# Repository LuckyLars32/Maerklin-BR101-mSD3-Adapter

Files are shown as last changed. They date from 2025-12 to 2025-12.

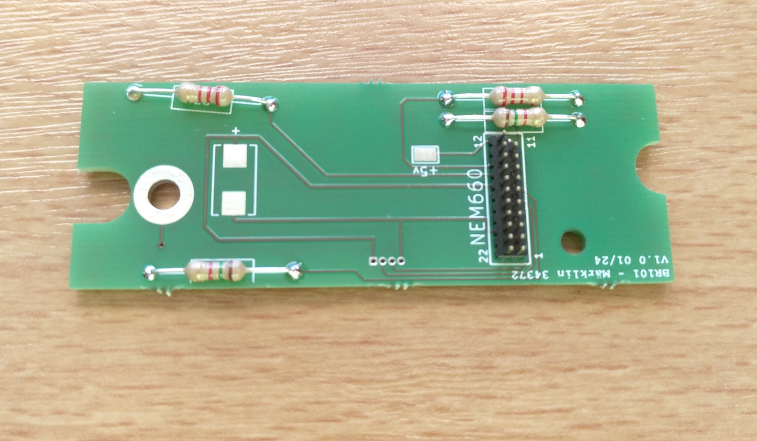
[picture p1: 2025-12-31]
BR101-mSD3-Adapterplatiene.png

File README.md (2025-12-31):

# Maerklin BR101 mSD3 Adapter
Adapterplatiene und Schallkapsel für den Einbau eines mSD3 Decoders + HLA in die Märklin BR101.  
Die Platine habe ich mit KiCAD Version 7.X erstellt.  
Die Schallkapsel habe ich mit einer 0.4er Düse, 0.2mm Layerhöhe und 50% Infill gedruckt.  

# Materialliste / BOM:
4x Widerstand 2,2 kΩ Bauform 0207 (der normale through-hole)  
1x 24 Pin Steckleiste (Push-Pull) gerade mit 1,27mm Raster  
1x Keramikkondensator 1206 (3216 metrisch) 1UF  
1x Märklin HLA Nachrüst Set 60941  
1x Märklin mSD3 oder anderer Sounddecoder mit NEM 660 Schnitstelle  
1x 15x11x3mm Lautsprecher 4-8 Ohm  

# Zusammenbau
Einbauseite immer wie Bedruckung auf der Platiene.
Die Wiederstände R1, R2, R3, R4 werden mit den 4x Widerstand 2,2 kΩ Bauform 0207 bestückt.
Die NEM660 Schnittstelle wird mit der 24 Pin Steckleiste mit 1,27mm Raster bestückt.
Der Keramikkondensator 1206 mit 1UF muss auf die Pads zwischen R1 und R3

# Pufferschaltung über mSD3 SUSI
Zusätzlich benötigte Komponenten:
2x Elko mit 500 - 1000 UF und max. 8,2 x 20 mm Radial
1x Schottkydiode mit 2 A Stromfestigkeit 25V Spannungsfestigkeit (mehr geht auch)
1x Widerstand 100 Ω
Zusammenbau:
Die beiden Elkos Paralell schalten. Dann die Scotty-Diode Parelell zum Wiederstand mit der + seite der Elkos verbinden.
Einbau:
Die Pufferschaltung dann mit +UB (+) und GND (-) auf der Adapterplatiene (bei eingebauter Platiene oben) verbinden.
Alternativ kann die Pufferschaltung auch an die Kontakte für den auf der Platiene integrierten Kondensator (bei eingebauter Platiene unten) angeschlossen werden. 
Diese Lötpads sind ebenso mit +UB und GND verbunden.

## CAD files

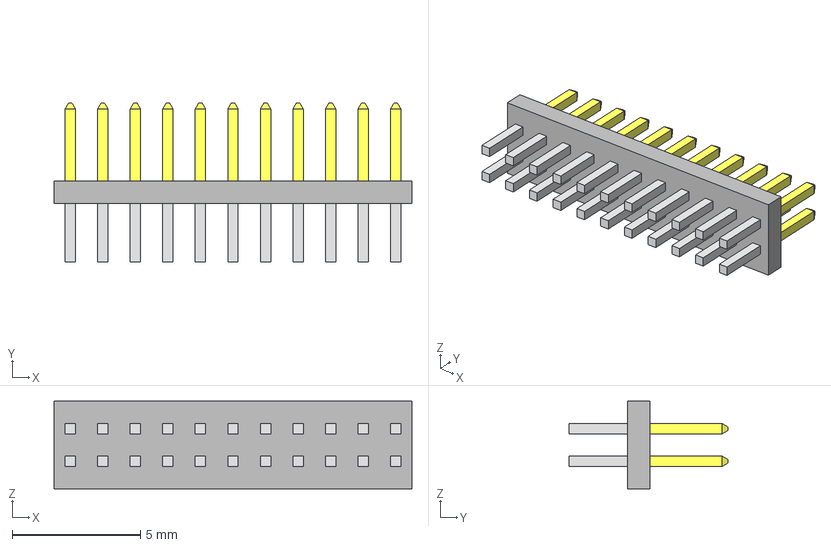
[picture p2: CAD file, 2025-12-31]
Maerklin_sMD3_Traegerplatiene_BR101/MaerklinConnectors/SAMTEC-FTS-111-01-X-D.step
14.0 x 6.20 x 3.43 mm
FTS-111-01-L-D_pins2
FTS-111-01-L-D_pins1
FTS-111-01-L-D_body

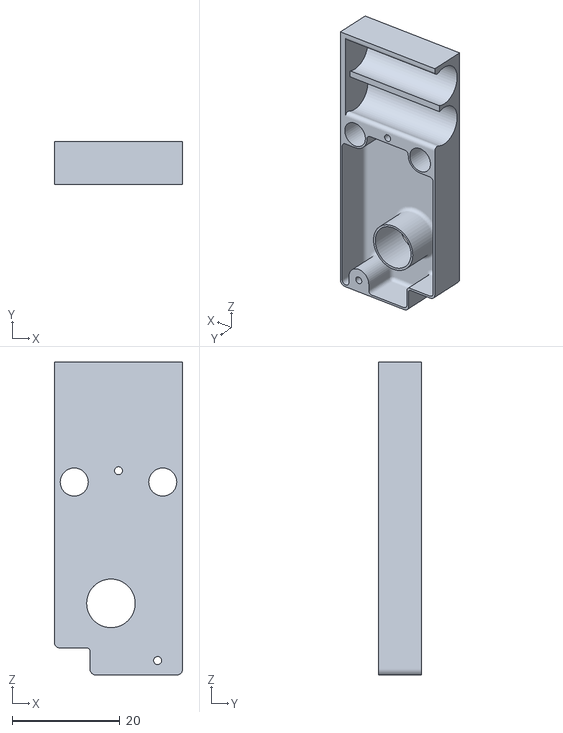
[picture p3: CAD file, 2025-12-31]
Schallkapsel/SchallkapselBR101.stl
23.8 x 8.00 x 58.0

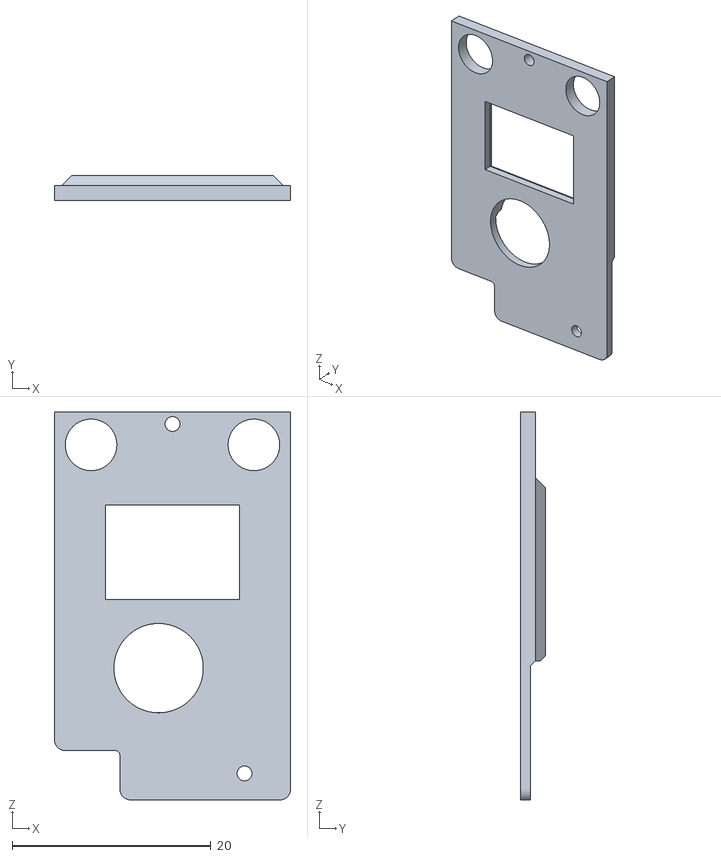
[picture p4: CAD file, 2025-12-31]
Schallkapsel/SchallkapselDeckelBR101.stl
23.8 x 2.50 x 39.1

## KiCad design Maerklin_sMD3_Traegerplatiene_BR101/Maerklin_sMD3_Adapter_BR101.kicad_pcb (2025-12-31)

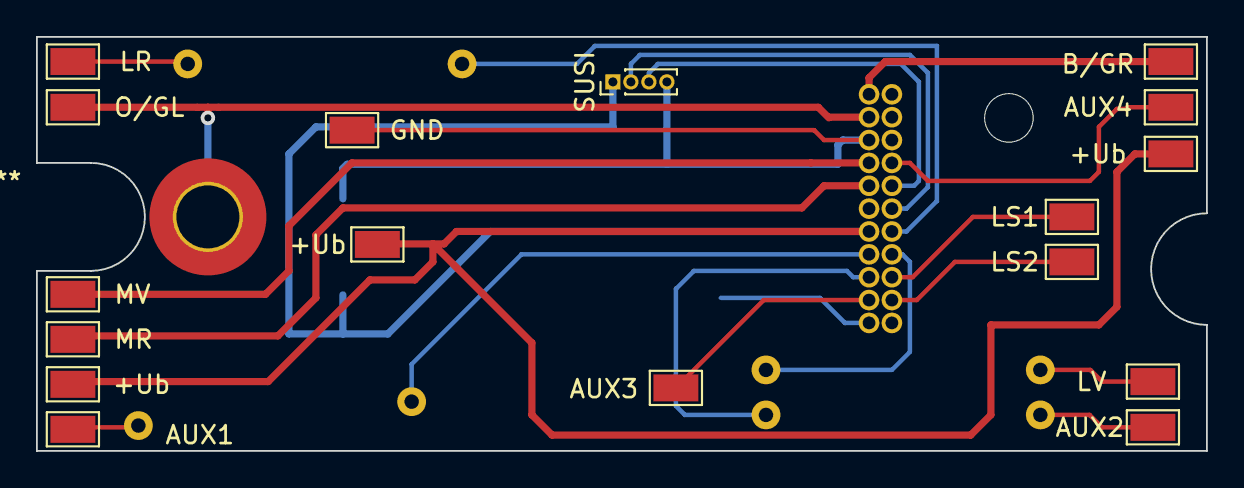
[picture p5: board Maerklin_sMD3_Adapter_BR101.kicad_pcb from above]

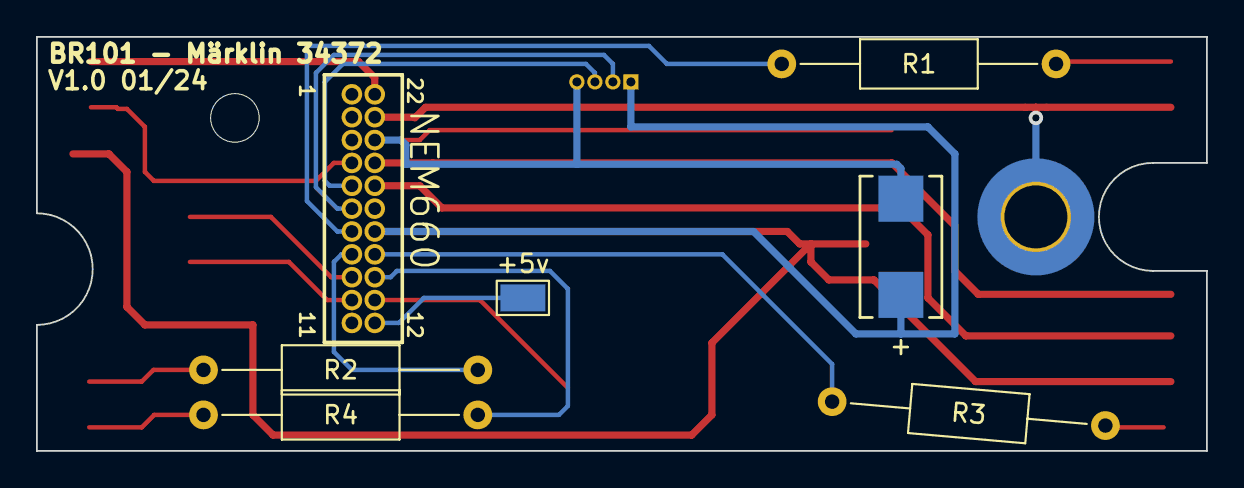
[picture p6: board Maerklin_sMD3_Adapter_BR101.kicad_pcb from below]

Board: 2 copper layers, 65.0 x 23.0 mm, 24 parts (7 on the bottom side), 21 nets.

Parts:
+5v: +5v; TestPoint_Pad_1.5x2.5mm
+Ub: +Ub; TestPoint_Pad_1.5x2.5mm
+Ub#2, +Ub#3: +Ub; TestPoint_Pad_1.5x2.5mm
AUX1: AUX1; TestPoint_Pad_1.5x2.5mm
AUX2: AUX2; TestPoint_Pad_1.5x2.5mm
AUX3: AUX3; TestPoint_Pad_1.5x2.5mm
AUX4: AUX4; TestPoint_Pad_1.5x2.5mm
B/GR: B/GR; TestPoint_Pad_1.5x2.5mm
C1: T491X108K006AT; CAPMP7.6X4.3_4.3N_KEM
GND: GND; TestPoint_Pad_1.5x2.5mm
LR: LR; TestPoint_Pad_1.5x2.5mm
LS1, LS2: LS; TestPoint_Pad_1.5x2.5mm
LV: LV; TestPoint_Pad_1.5x2.5mm
MR: MR; TestPoint_Pad_1.5x2.5mm
MV: MV; TestPoint_Pad_1.5x2.5mm
NEM660: SAMTEC-FTS-111-01-X-D
O/GL: O/GL; TestPoint_Pad_1.5x2.5mm
R1, R2, R3, R4: R_Axial_DIN0207_L6.3mm_D2.5mm_P15.24mm_Horizontal
SUSI: SUSI; PinHeader_1x04_P1.00mm_Vertical

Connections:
0/GL: NEM660.21, O/GL.1
+5v: +5v.1, NEM660.12
+Ub: +Ub.1, +Ub#2.1, +Ub#3.1, C1.1, NEM660.16, SUSI.1
AUX1: AUX1.1, R3.2
AUX2: AUX2.1, R4.2
AUX3: AUX3.1, NEM660.13
AUX4: AUX4.1, NEM660.4
B/GR: B/GR.1, NEM660.22
GND: C1.2, GND.1, NEM660.20, SUSI.4
LR: LR.1, R1.1
LS1: LS2.1, NEM660.10
LS2: LS1.1, NEM660.9
LV: LV.1, R2.1
MR: MR.1, NEM660.18
MV: MV.1, NEM660.19
unnamed: NEM660.7, R1.2
unnamed: NEM660.8, R2.2
unnamed: NEM660.14, R4.1
unnamed: NEM660.15, R3.1
SUSI2: NEM660.6, SUSI.2
SUSI3: NEM660.5, SUSI.3

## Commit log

2025-12-31 Initiale Version der README.md
2025-12-31 Bild von BR101 mSD3 Adapterplatiene
    Bild von BR101 mSD3 Adapterplatiene fertig Assembliert.
    Der Keramikkondensator ist hier nicht bestückt da bei nutzung der Pufferschaltung nicht zwingend nötig.

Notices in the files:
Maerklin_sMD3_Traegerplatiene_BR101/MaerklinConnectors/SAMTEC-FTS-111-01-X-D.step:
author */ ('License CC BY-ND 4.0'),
